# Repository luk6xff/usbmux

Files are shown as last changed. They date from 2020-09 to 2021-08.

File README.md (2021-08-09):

# usbmux
USB 2.0  two input channel multiplexer based on TS3USB221

## Details
A simple USB2.0 2-channel multiplexer controlled using: UART(Serial) CLI and HTTP server available running at: `usbmux.local`.

## Instalation
* Install `vscode` with `platformio` plugin (Versions: vscode[1.49.2], platformio[Core:5.0.1, Home:3.3.0])

## Building and flashing
```sh
# Build an application
platformio run

# Build filesystem
platformio run --target buildfs --environment d1_mini

# Upload filesystem image
platformio run --target uploadfs --environment d1_mini

# Upload the application binary
platformio run --target upload

# All in one-liner
platformio run  &&  platformio run --target buildfs --environment d1_mini  &&  platformio run --target uploadfs --environment d1_mini  &&  platformio run --target upload
```

## Pinout
* HW pinout defined at: `usbmux/app/src/hw_config.h`
* Board connector pinout:
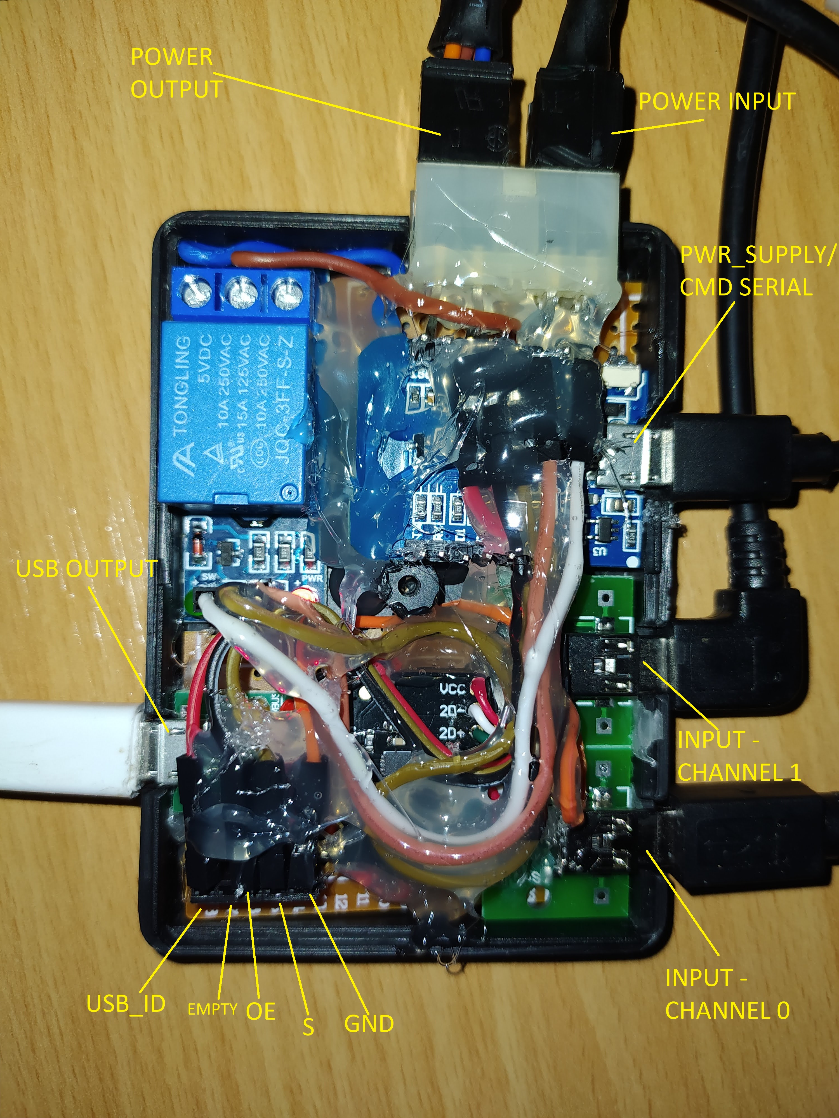
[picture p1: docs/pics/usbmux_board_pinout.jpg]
usbmux_board_pinout


## Schematics
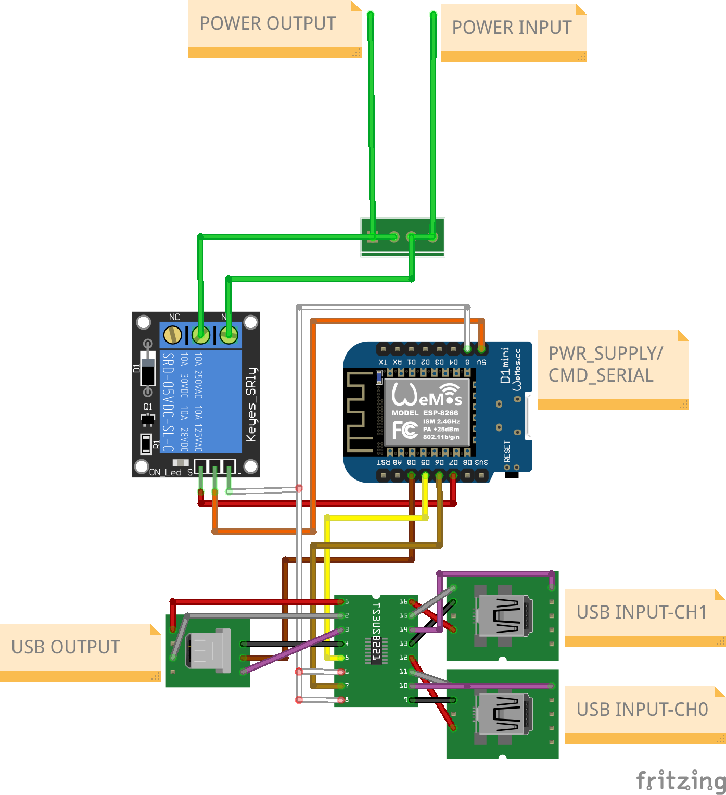
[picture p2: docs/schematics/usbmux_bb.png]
usbmux_board_schematics


## More random pics
* Completed device:
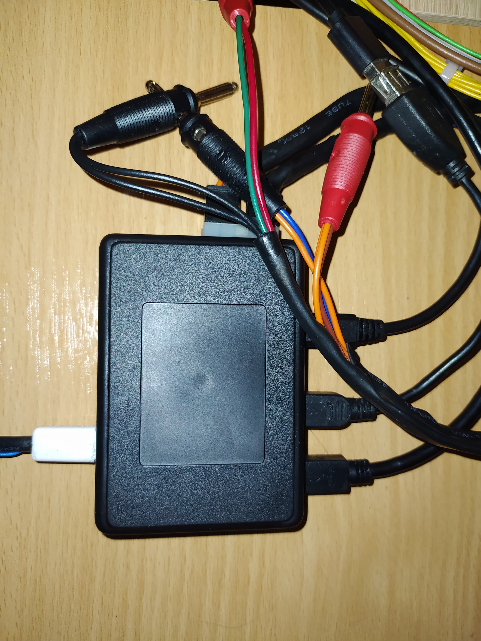
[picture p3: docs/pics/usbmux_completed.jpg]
usbmux_completed

* UART(Serial) CLI:
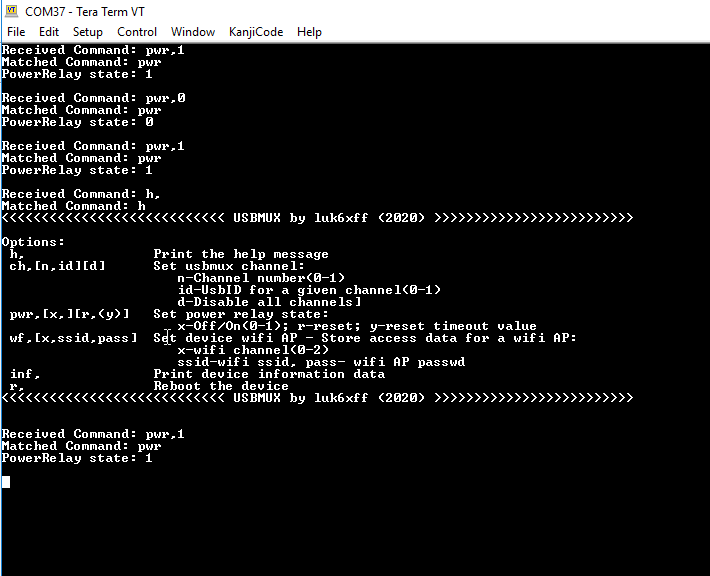
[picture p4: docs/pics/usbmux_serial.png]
usbmux_web1

* Web server:
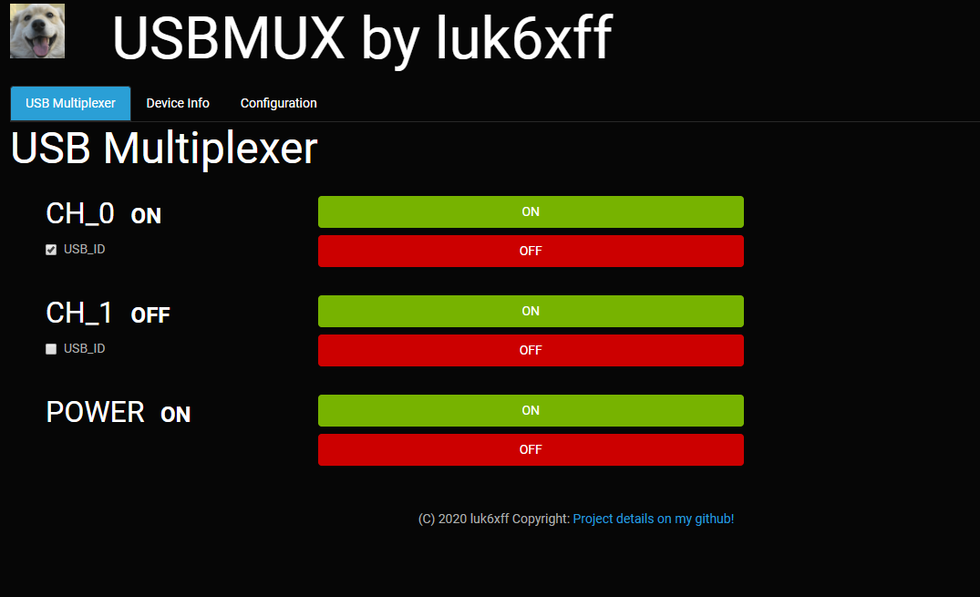
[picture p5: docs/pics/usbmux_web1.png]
usbmux_web1

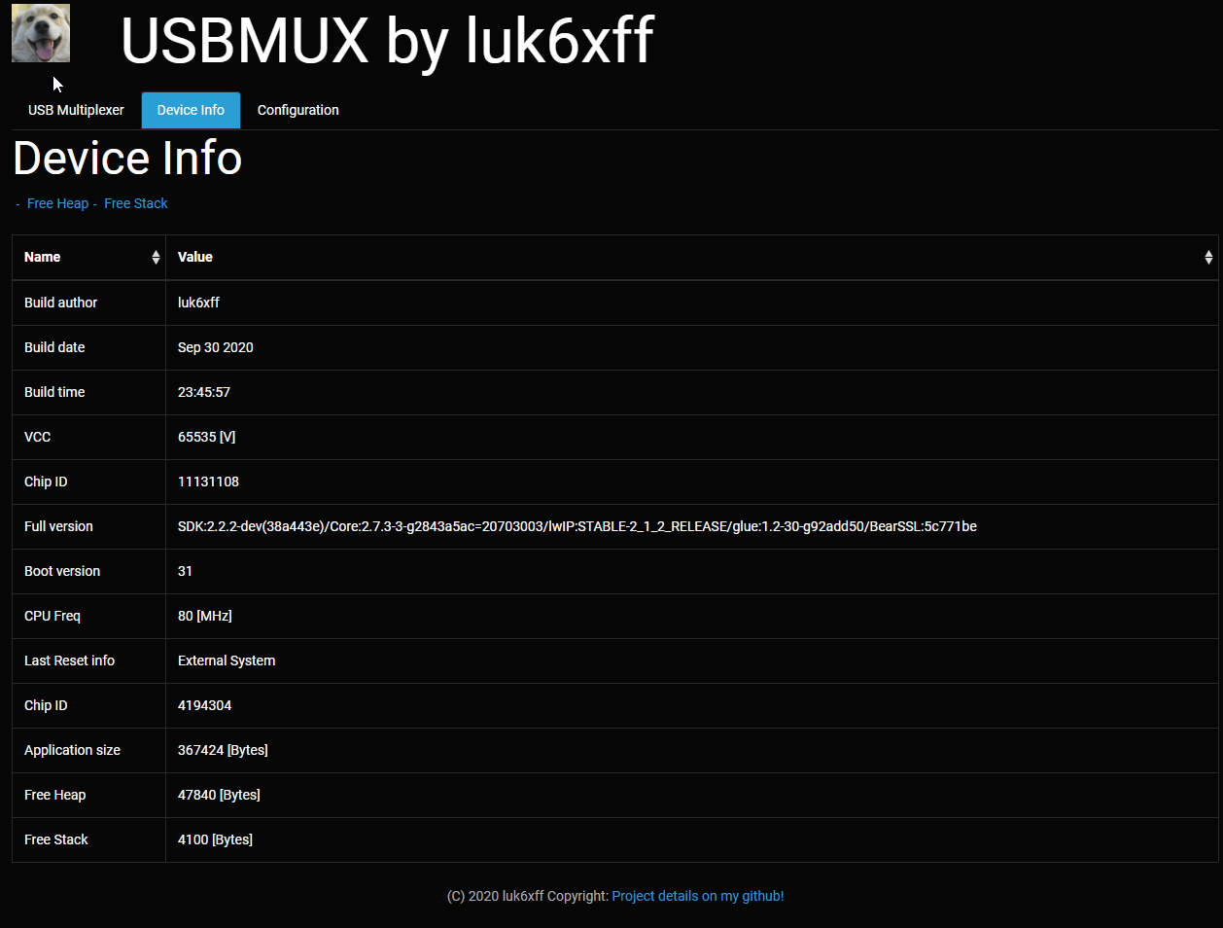
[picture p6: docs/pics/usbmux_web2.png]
usbmux_web2


## BOM

| PART NAME | SHOP LINK | DATASHEET | QUANTITY | PRICE [PLN] |
|---|---|---|---|---|
| ESP8266 WEMOS D1-MINI | [AliExpress](https://aliexpress.com/item/32845061455.html)|[ESP8266-D1MINI](./https://docs.wemos.cc/en/latest/d1/d1_mini.html) | 1 | 7.99 |
| TS3USB221 - USB 2.0 Mux | [AliExpress](https://aliexpress.com/item/32890652381.html) |[TS3USB221](./app/lib/TS3USB221/docs/ts3usb221.pdf) | 1 | 6.00 |
| Relay module | [AliExpress](https://aliexpress.com/item/4000295545270.html) | - | 1 | 2.09 |
| CASE type: Z23  | [Allegro](https://allegro.pl/oferta/z-23-obudowa-z-tworzywa-84x59x30mm-polistyren-z23-8519706140) | [Z23](./docs/datasheet/Z23.pdf) | 1 | 3.39 |
| Micro USB 2.0 male connector | [Allegro](https://allegro.pl/oferta/wtyk-micro-mikro-usb-typu-b-montaz-na-kabel-0217a-8100421172) | - | 1 | 1.20 |
| Mini USB 2.0 male connector | [Allegro](https://allegro.pl/oferta/wtyk-wtyczka-mini-usb-5p-5pin-typ-b-na-kabel-1947a-8504618684) | - | 1 | 1.40 |
| Micro USB 2.0 female to DIP Adapter | [Allegro](https://allegro.pl/oferta/plytka-adapter-micro-usb-2-0-zenska-switch-dip-5p-8851640680) | - | 1 | 2.29 |
| Mini USB 2.0 female to DIP Adapter | [Allegro](https://allegro.pl/oferta/plytka-adapter-mini-usb-dip-5p-wtyczka-zenska-8130118409) | - | 1 | 2.29 |
|  |  |  |  | = 26.65 |

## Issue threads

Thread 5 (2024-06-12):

Can't see mux/demux board pin connections.

sethstenzel, 2024-06-12:
Say I have a project and was looking how to use that black mux/demux board.
There is a lot of hot glue and I can't see how that black breakout board is connected to your sub board to match pins up.
Do you have any more details on this or the usage of that smaller black board or do you have some pictures with less glue :D?

luk6xff, 2024-06-15:
Hi @sethstenzel

Will this be enough: https://github.com/luk6xff/usbmux/blob/master/docs/schematics/usbmux_bb.png ?

sethstenzel, 2024-06-16:
If you labeled the diagram it would be. There are some non-standard colors being used for the wires, and the fritz diagram of the demux break looks completely different then the real one so without the wires labeled it's hard to know what's going on. I suppose I can read through the code and try to work it out if you labeled this pretty clearly in code.

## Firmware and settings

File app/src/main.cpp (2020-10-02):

#include "utils.h"
#include "app-settings.h"
#include "dev-server.h"
#include "serial-cmdhandler.h"


//------------------------------------------------------------------------------
static Commander cmdr;
static DevServer server(cmdr);
static SerialCmdHandler serCmdHandler(cmdr);

//------------------------------------------------------------------------------
void setup()
{
    utils::init();
    AppSettings::instance().init();
    server.init();
}

//------------------------------------------------------------------------------
void loop()
{
    server.process();
    serCmdHandler.process();
}

//------------------------------------------------------------------------------

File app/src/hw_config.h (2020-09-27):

/**
 * @brief USBMUX project - Hardware Pin configuration config file.
 */

// USB multiplexer - TS3USB221
#define USBMUX_OE_PIN   D5
#define USBMUX_S_PIN    D6

// USB_ID
#define USB_ID_PIN      D0

// RELAY
#define RELAY_IN_PIN    D7

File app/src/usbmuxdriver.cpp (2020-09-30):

#include "usbmuxdriver.h"
#include "utils.h"
#include "hw_config.h"

//------------------------------------------------------------------------------
UsbMuxDriver::UsbMuxDriver(int usbIdPin)
    : m_usbIdPin(usbIdPin)
{
    m_usbMuxArduinoDev.oe_pin = USBMUX_OE_PIN;
    m_usbMuxArduinoDev.s_pin  = USBMUX_S_PIN;
    ts3usb221_arduino_init(&m_usbMuxDev, &m_usbMuxArduinoDev);
    // Set USB_ID pin
    pinMode(m_usbIdPin, OUTPUT);
    digitalWrite(m_usbIdPin, USB_ID_HIGH);
}

//------------------------------------------------------------------------------
void UsbMuxDriver::enableChannel(UsbChannelNumber chNumber, UsbIdState idState)
{
    if (!isChannelValid(chNumber))
    {
        err("Invalid usb mux channel number: %d!\n", chNumber);
        return;
    }

    if (chNumber == USB_CHANNEL_0)
    {
        ts3usb221_enable_1D_channel(&m_usbMuxDev);
    }

    else if (chNumber == USB_CHANNEL_1)
    {
        ts3usb221_enable_2D_channel(&m_usbMuxDev);
    }

    // Set USB_ID pin state
    digitalWrite(m_usbIdPin, idState);

}

//------------------------------------------------------------------------------
void UsbMuxDriver::disableAll()
{
    ts3usb221_low_power_mode(&m_usbMuxDev);
    digitalWrite(m_usbIdPin, USB_ID_HIGH);
}


//------------------------------------------------------------------------------

bool UsbMuxDriver::isChannelValid(UsbChannelNumber chNumber)
{
    return (chNumber < UsbChannelNumber::USB_CHANNEL_INVALID) ? true : false;
}


//------------------------------------------------------------------------------
